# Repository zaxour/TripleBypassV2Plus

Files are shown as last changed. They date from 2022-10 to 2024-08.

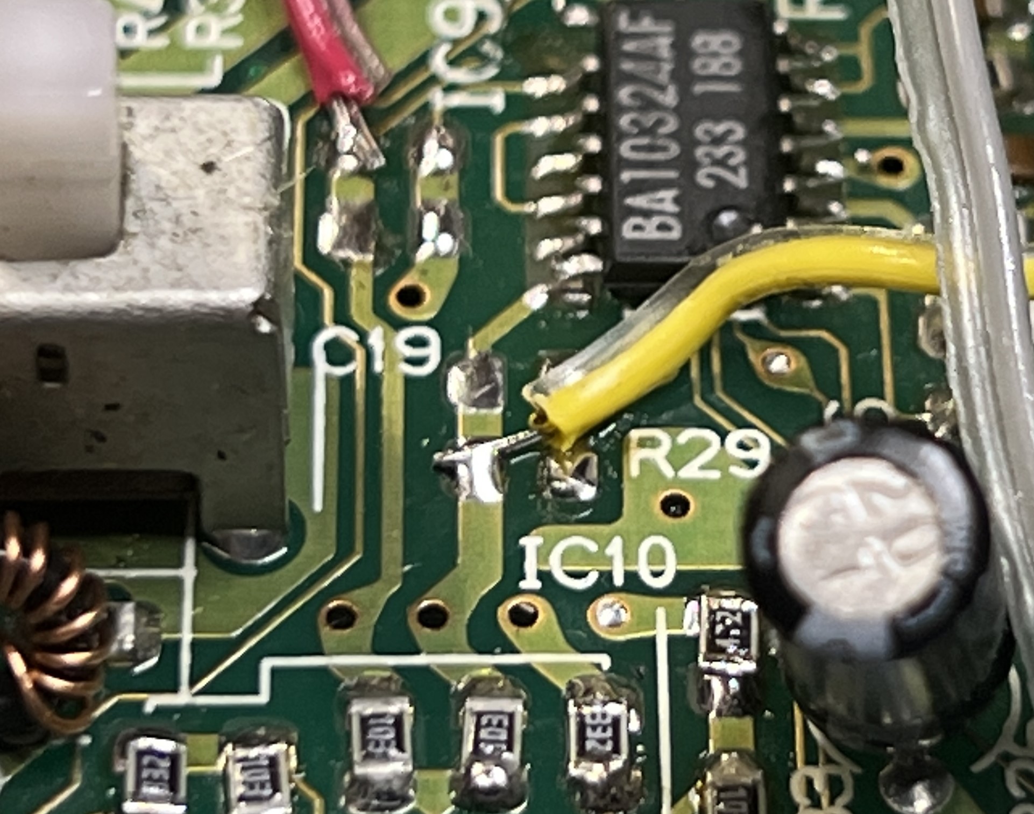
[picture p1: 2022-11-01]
images/Headphone Amp Connections.jpg

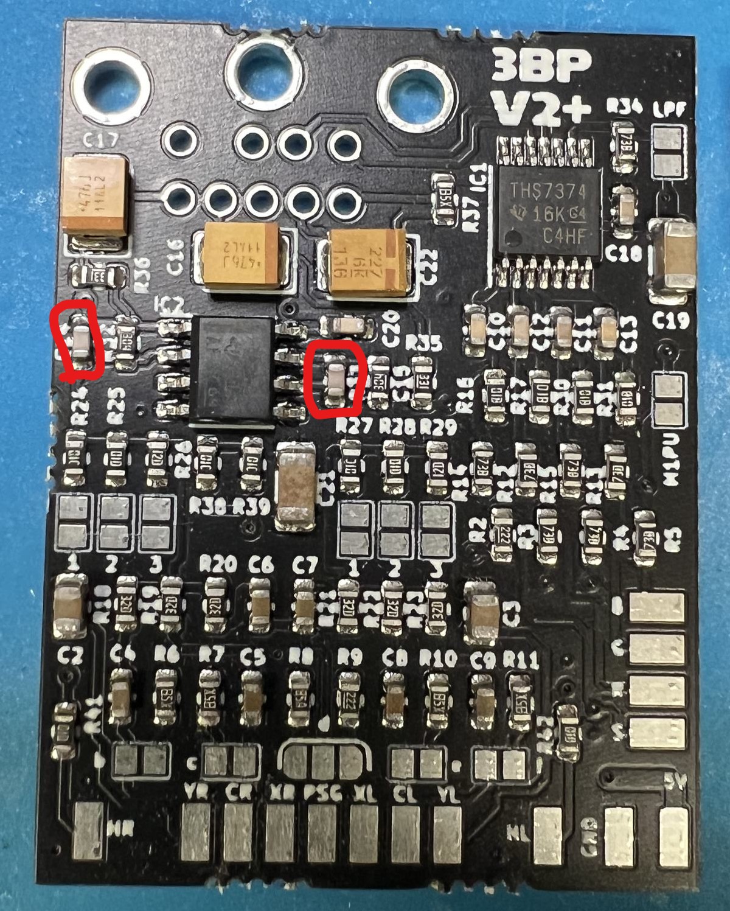
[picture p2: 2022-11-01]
images/3BP_RemoveCaps.jpg

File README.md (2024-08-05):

# Triple Bypass V2 Plus
My variant of Tian Feng's Triple Bypass V2, integrating pull up resistors and headphone restoration capability for Model 1 installs, as well as composite video restoration capability for all models.

All Genesis/Mega Drive revision instructions are linked below:

## Model 1 Installation Guides
[Model 1 - VA1-VA6](https://github.com/zaxour/TripleBypassV2Plus/blob/main/Documentation/3BP%20-%20M1VA0-VA6.pdf) 

[Model 1 - VA7](https://github.com/zaxour/TripleBypassV2Plus/blob/main/Documentation/3BP%20-%20M1VA7.pdf)
## Model 2 Installation Guides
[Model 2 - VA0-1.8](https://github.com/zaxour/TripleBypassV2Plus/blob/main/Documentation/3BP%20-%20M2VA0-1_8.pdf)

[Model 2 - VA2](https://github.com/zaxour/TripleBypassV2Plus/blob/main/Documentation/3BP%20-%20M2VA2.pdf)

[Model 2 - VA2.3](https://github.com/zaxour/TripleBypassV2Plus/blob/main/Documentation/3BP%20-%20M2VA2_3.pdf)

[Model 2 - VA3](https://github.com/zaxour/TripleBypassV2Plus/blob/main/Documentation/3BP%20-%20M2VA3.pdf)

[Model 2 - VA4](https://github.com/zaxour/TripleBypassV2Plus/blob/main/Documentation/3BP%20-%20M2VA4.pdf)

## Model 3 Installation Guides
[Model 3 - VA1](https://github.com/zaxour/TripleBypassV2Plus/blob/main/Documentation/3BP%20-%20M3VA1.pdf)

[Model 3 - VA2](https://github.com/zaxour/TripleBypassV2Plus/blob/main/Documentation/3BP%20-%20M3VA2.pdf)

## Sega CDX
[CDX](https://github.com/zaxour/TripleBypassV2Plus/blob/main/Documentation/3BP%20-%20CDX.pdf)

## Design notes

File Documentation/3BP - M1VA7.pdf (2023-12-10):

## Model 1 VA7 Procedure

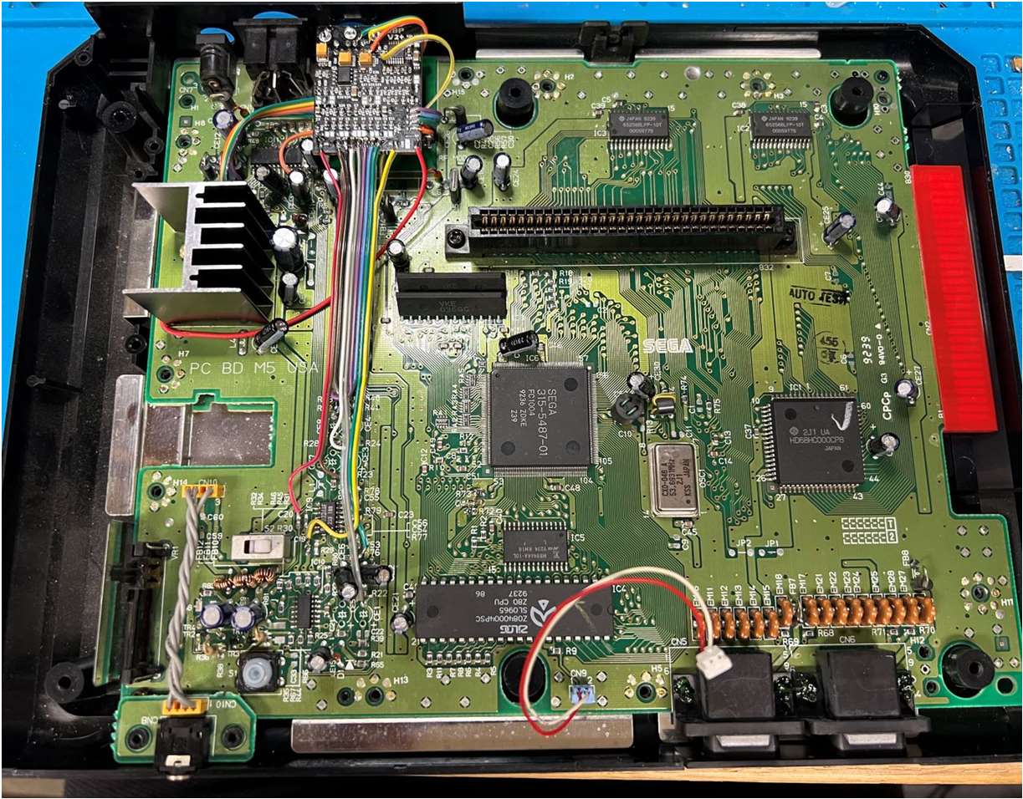
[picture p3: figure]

## Model 1 VA7 – Audio – Component Removal

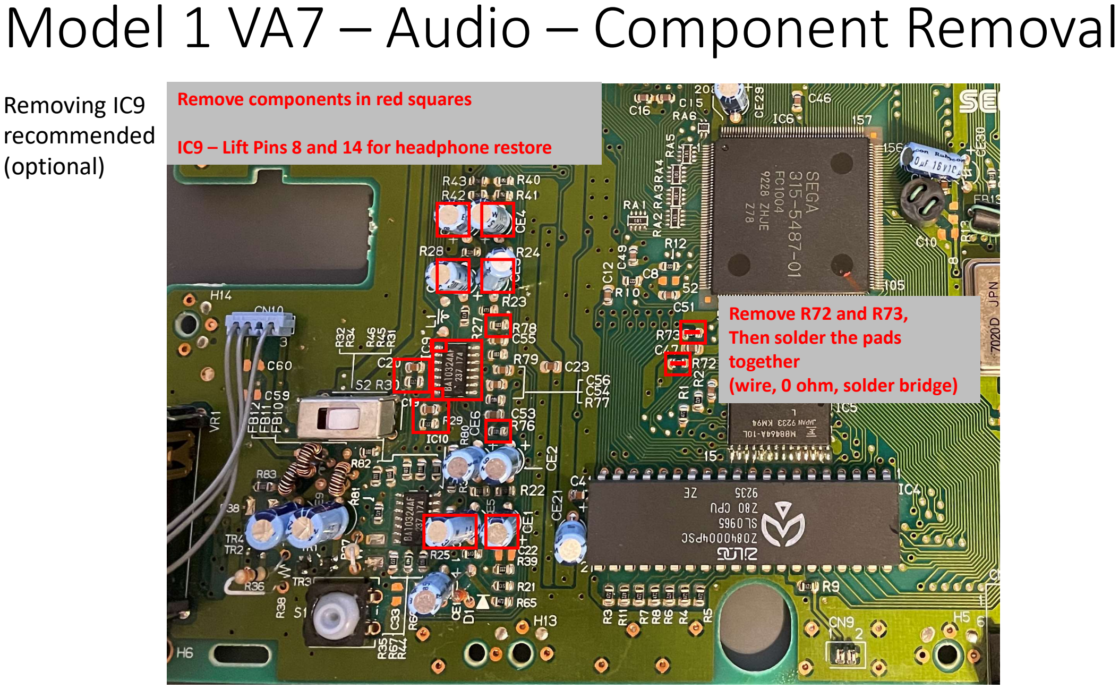
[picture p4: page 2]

Remove R72 and R73,
Then solder the pads
together
(wire, 0 ohm, solder bridge)

Remove components in red squares

IC9 – Lift Pins 8 and 14 for headphone restore

Removing IC9
recommended
(optional)

## Model 1 VA7 – Audio – Signal Points

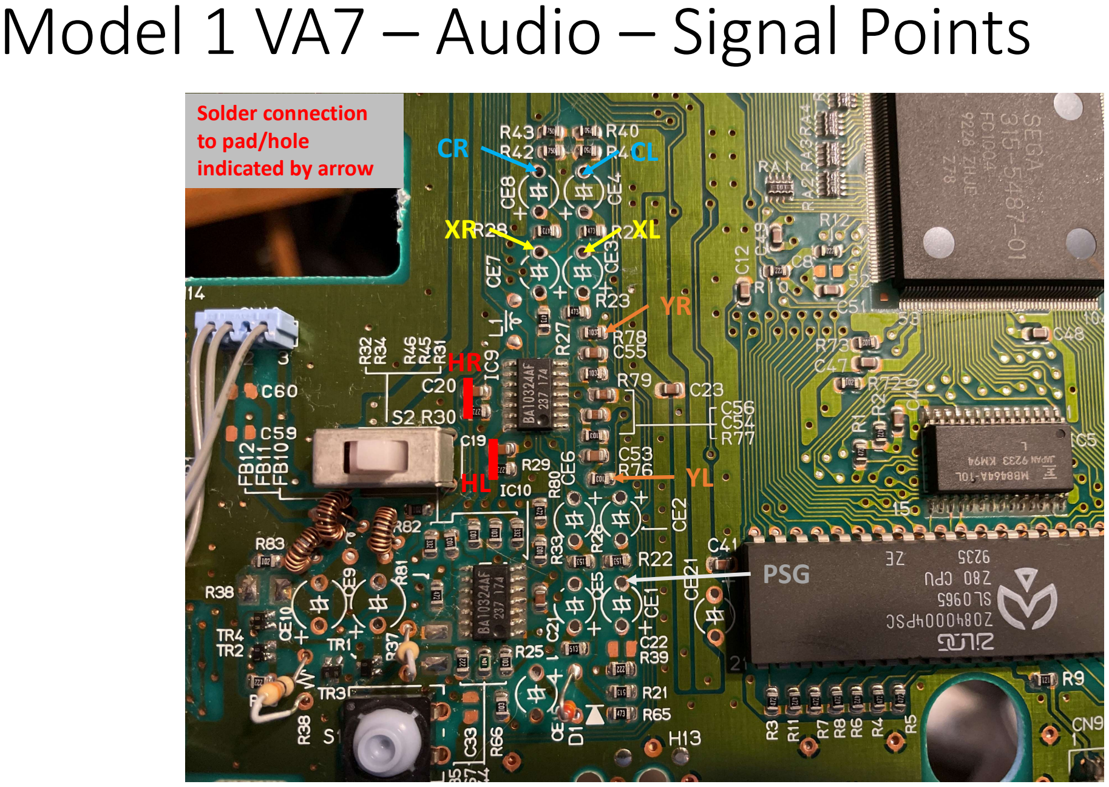
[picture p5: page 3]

CR | CL
XR | XL YR

YL

PSG

Solder connection
to pad/hole
indicated by arrow

HR

HL

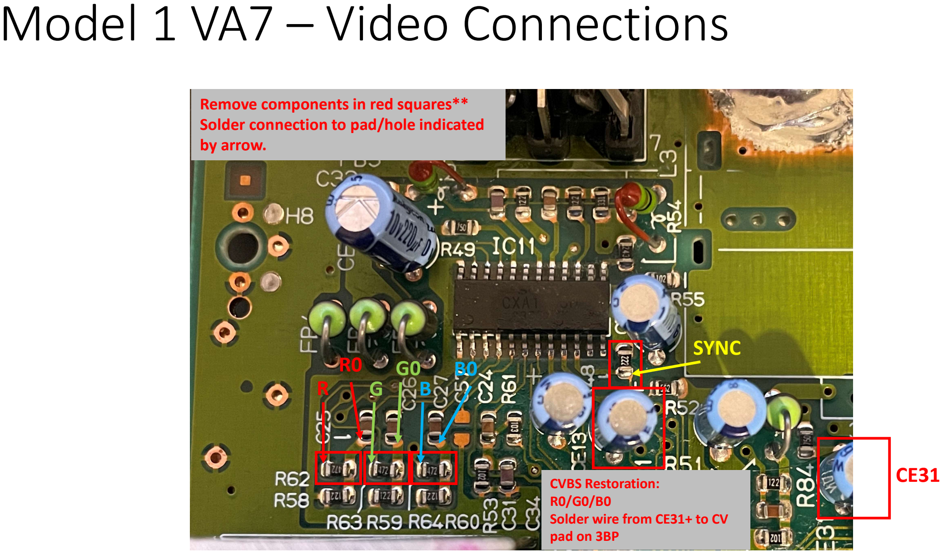
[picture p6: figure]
Model 1 VA7 – Video Connections; SYNC; Remove components in red squares** Solder connection to pad/hole indicated by arrow.; CVBS Restoration: R0/G0/B0 Solder wire from CE31+ to CV pad on 3BP

## Model 1 VA7 – Supply Voltage

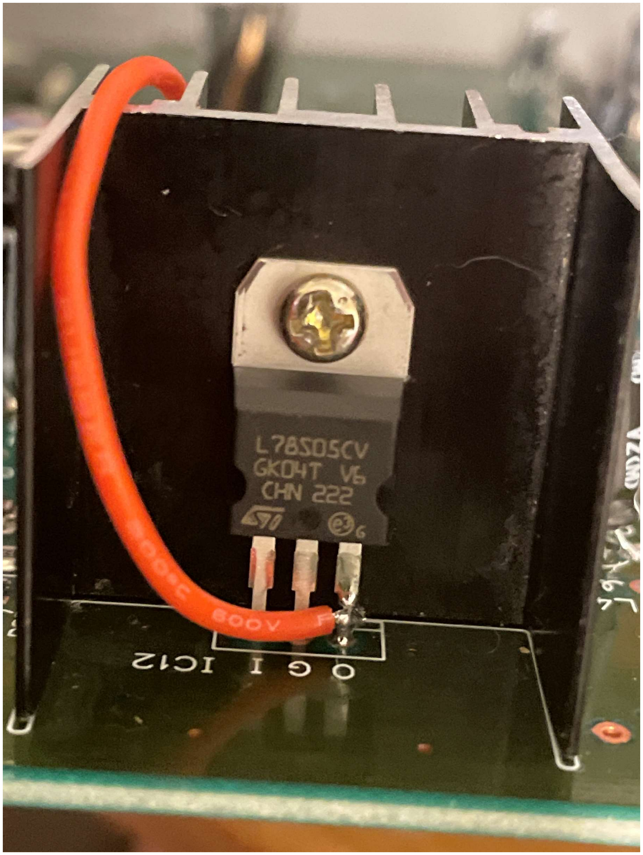
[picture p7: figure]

- Solder a wire from
the “O” (output) pin
of the 5V regulator
to the 5V pad on the
3BP to complete the
installation

## Model 1 VA7 – 3BP Jumpers and Wrap-Up

- ***If re-using the RF shield, remember to bend/cut any points that may contact the 3BP***
- Bridge the following solder jumpers:
- 2
- If NO CVBS restore – S75
- The other jumpers are unnecessary for this model using this guide.

## M1VA7 – Installation Complete w/ CVBS Restore and Headphone Restore

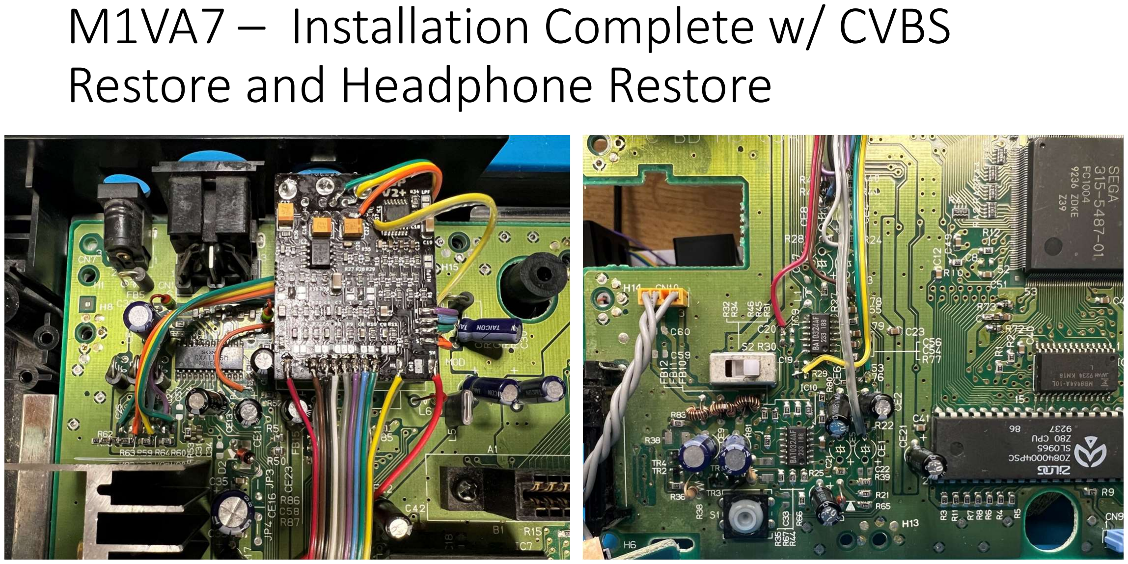
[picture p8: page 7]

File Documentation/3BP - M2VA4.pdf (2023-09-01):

# M2VA4 Procedure

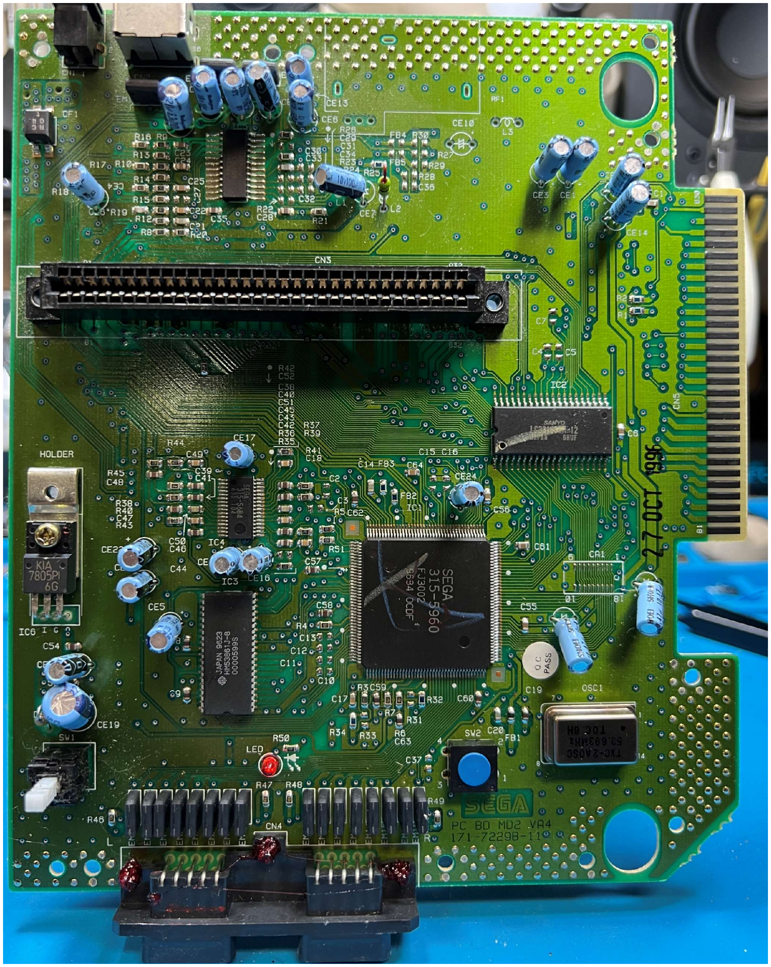
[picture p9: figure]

# M2VA4 – Audio – Component Removal

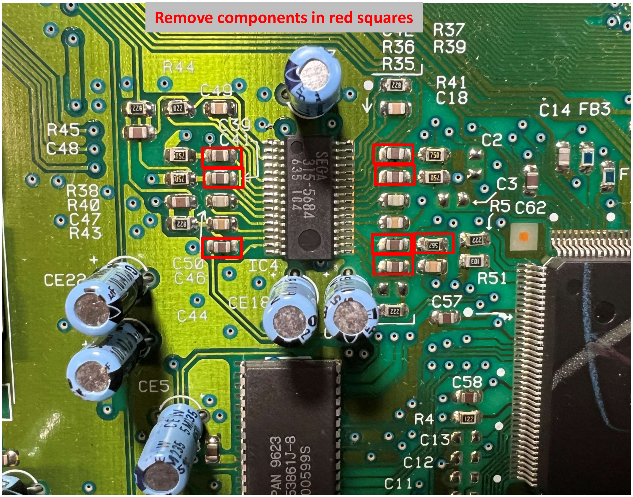
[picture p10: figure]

IC9 is required for | Remove components in red squares
system operation
(reset circuit,
reference voltage)

Also remove CE11-
12 (see Video
component
removal section)

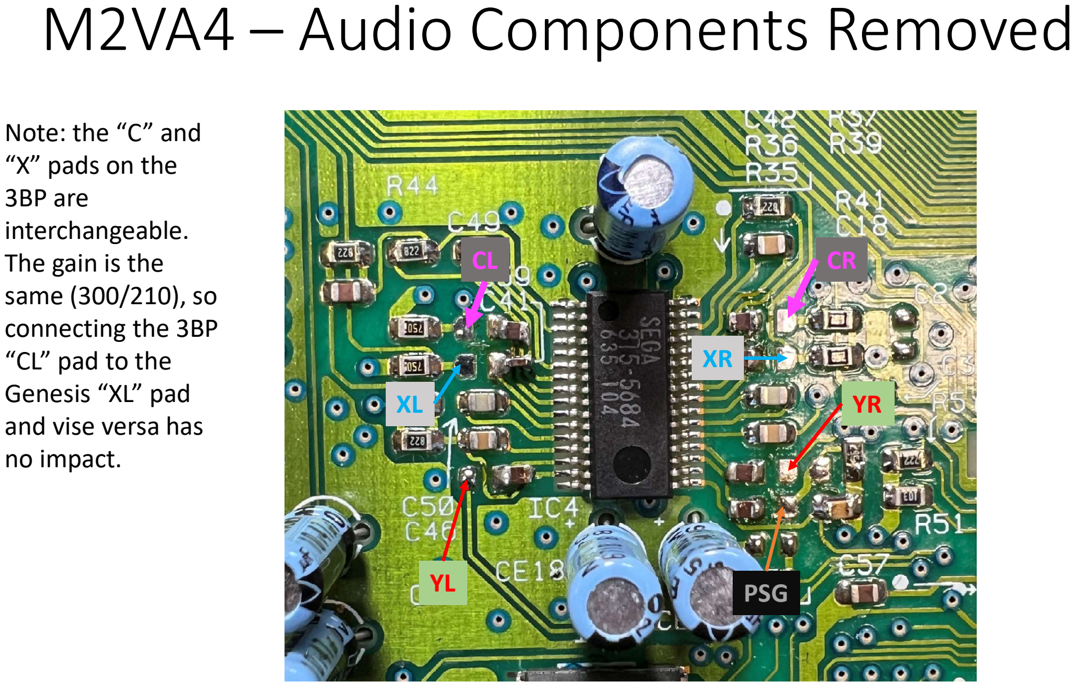
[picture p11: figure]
M2VA4 – Audio Components Removed; Note: the “C” and “X” pads on the 3BP are interchangeable. The gain is the same (300/210), so connecting the 3BP “CL” pad to the Genesis “XL” pad and vise versa has no impact.; PSG

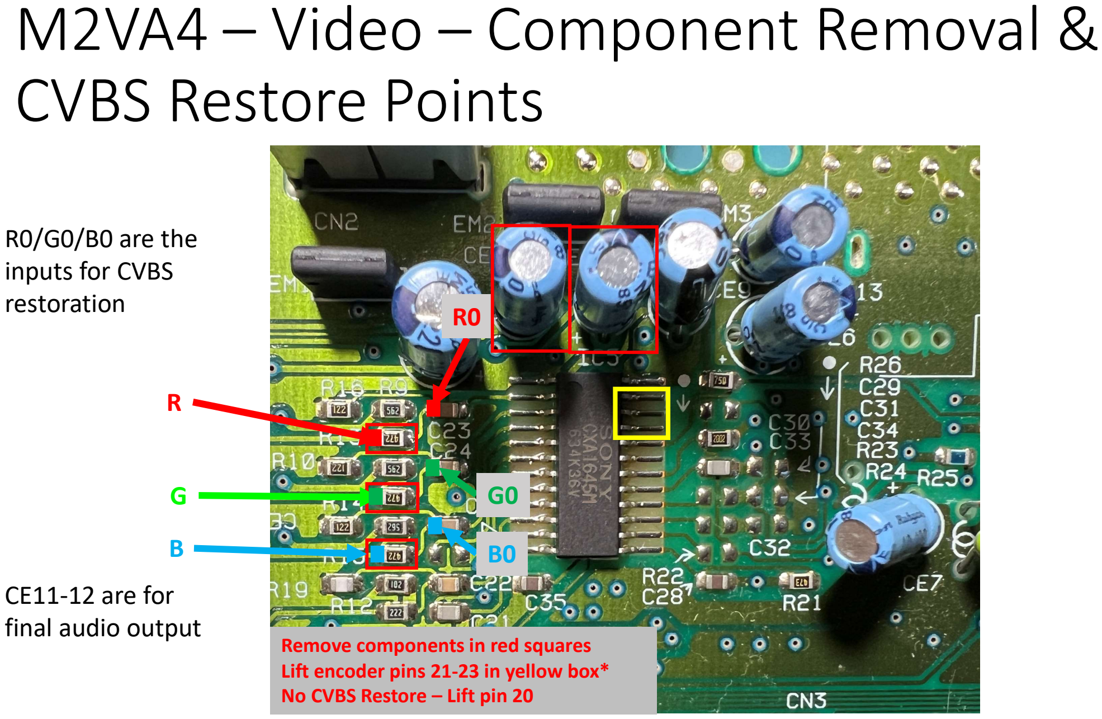
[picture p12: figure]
M2VA4 – Video – Component Removal & CVBS Restore Points; Remove components in red squares Lift encoder pins 21-23 in yellow box* No CVBS Restore – Lift pin 20; R0/G0/B0 are the inputs for CVBS restoration; CE11-12 are for final audio output

# M2VA4 – 3BP Jumpers

## - Solder the following jumpers:

## - 3 (both left and right) - D-Right - S75 if NOT restoring CVBS (V2A/V2+)

# M2VA4 Routing Complete

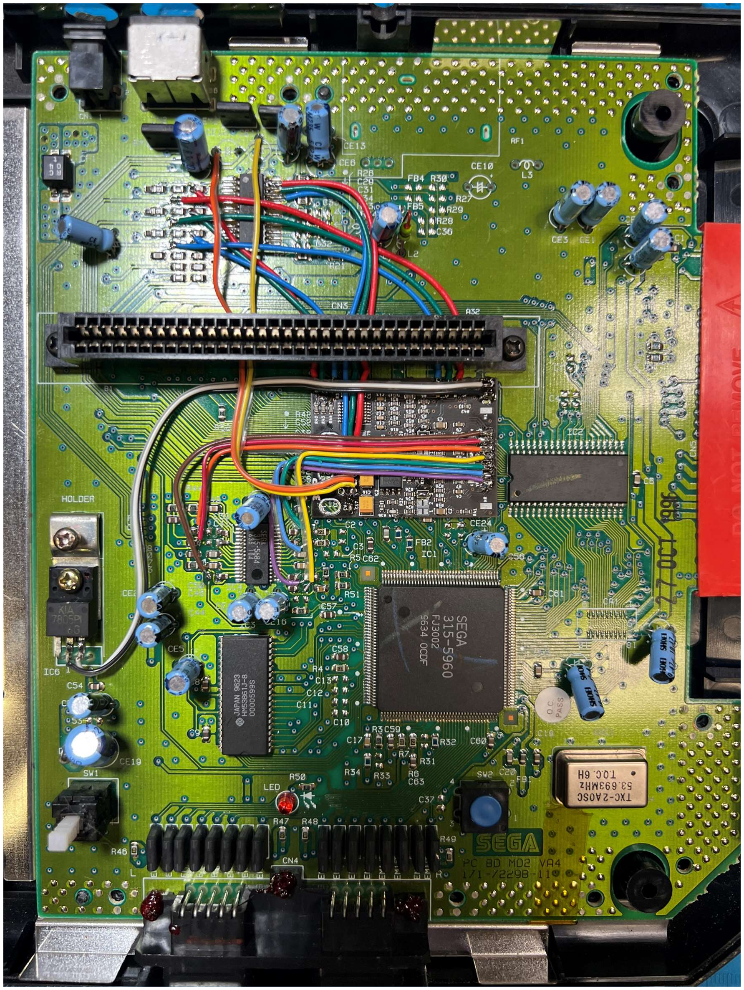
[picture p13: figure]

- If routing under the cart slot, it is
recommended to solder the RGB wires to the 3BP first, then pull the other end through the cart slot pins.

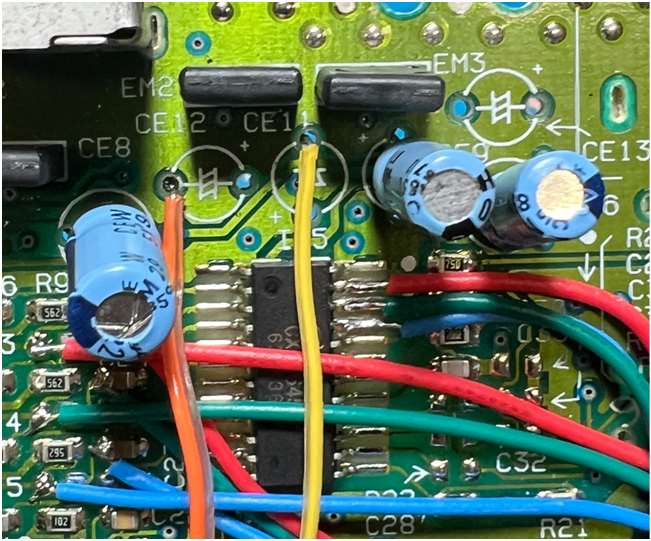
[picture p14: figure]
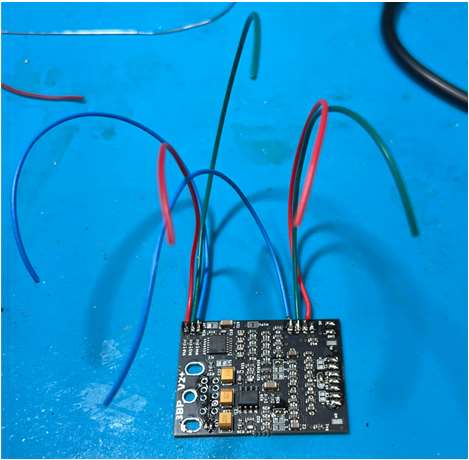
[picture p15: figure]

- CE11(-) – Right Audio
- CE12(-) – Left Audio

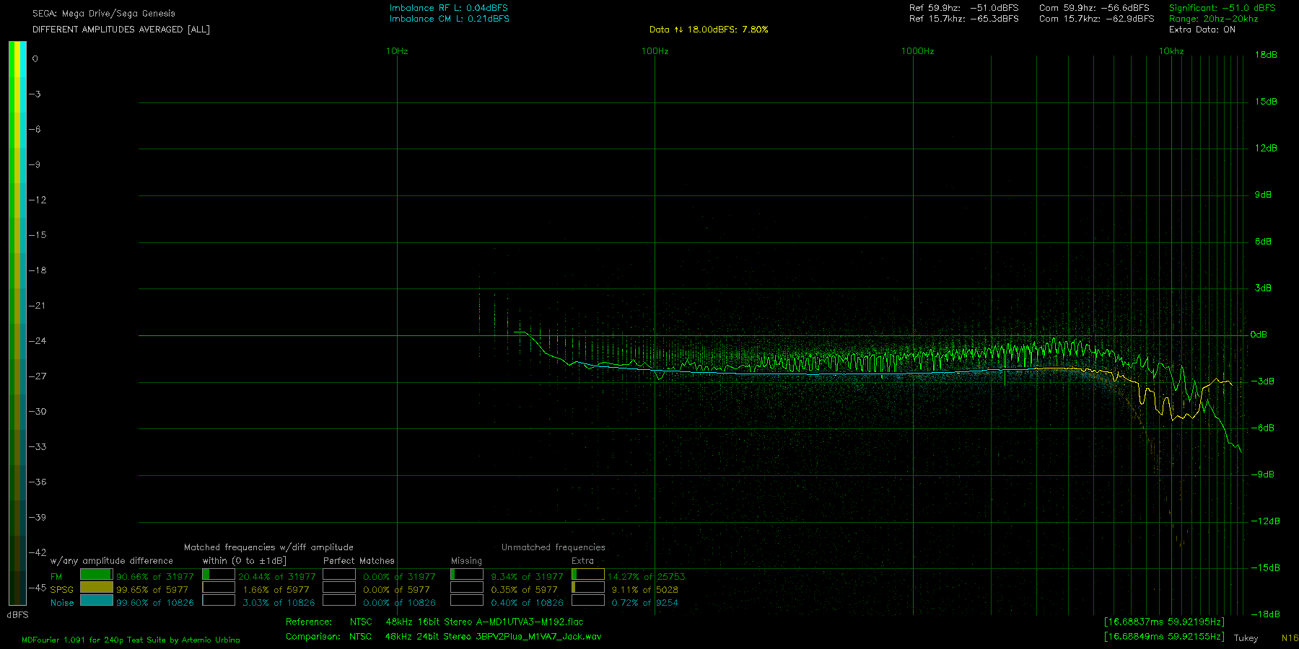
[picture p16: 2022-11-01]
images/DA__ALL_AVG_A-MD1UTVA3-M192_vs_3BPV2Plus_M1VA7_Jack_0000.png

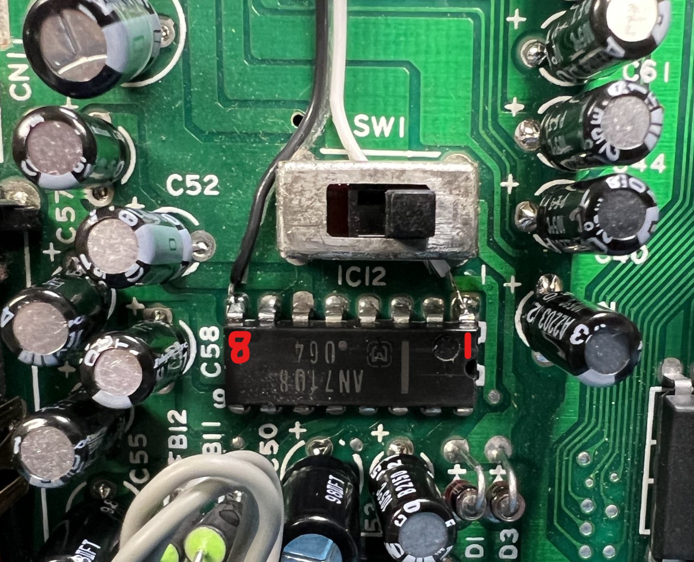
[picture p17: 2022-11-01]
images/VA3_HPAmp.jpg

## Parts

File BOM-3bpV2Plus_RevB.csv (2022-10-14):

Comment | Designator | Footprint | LCSC
220u | C22 | CP_EIA-3528-15_AVX-H | C122252
10u | C19,C21 | C_1206_3216Metric | C13585
0.1u | C10,C11,C12,C13,C18,C20 | C_0603_1608Metric | C14663
1u | C4,C5,C6,C7,C8,C9 | C_0603_1608Metric | C15849
10u | C2,C3 | C_0805_2012Metric | C15850
1k | R17,R30,R31 | R_0603_1608Metric | C21190
130k | R26,R29 | R_0603_1608Metric | C22795
210k | R18,R19,R20,R21,R22,R23 | R_0603_1608Metric | C22952
300k | R32,R33 | R_0603_1608Metric | C23024
330 | R35,R36 | R_0603_1608Metric | C23138
5.62k | R12,R13,R14,R15,R3,R34,R4,R5 | R_0603_1608Metric | C23188
750 | R8 | R_0603_1608Metric | C23241
100k | R25,R28,R41,R42 | R_0603_1608Metric | C25803
10k | R24,R27,R38,R39 | R_0603_1608Metric | C25804
THS7374IPWR | IC1 | TSSOP-14_4.4x5mm_P0.65mm | C2652746
150p | C14,C15 | C_0603_1608Metric | C37298
2.2k | R2,R9 | R_0603_1608Metric | C4190
75 | R10,R11,R6,R7 | R_0603_1608Metric | C4275
TL972 | IC2 | SOIC-8_3.9x4.9mm_P1.27mm | C46127
47u | C16,C17 | CP_EIA-3528-15_AVX-H | C7207
MD-90SM_MD2 | CN1 | MD90SM-MD2
SolderJumper_3_Open | D1 | SolderJumper-3_P1.3mm_Open_RoundedPad1.0x1.5mm
SolderJumper_2_Open | YR4 | SolderJumper-2
SolderJumper_2_Open | YR3 | SolderJumper-2
SolderJumper_2_Open | YR2 | SolderJumper-2
SolderJumper_2_Open | YL4 | SolderJumper-2
SolderJumper_2_Open | YL3 | SolderJumper-2
SolderJumper_2_Open | YL2 | SolderJumper-2
SolderJumper_2_Open | M1PU1 | SolderJumper-2
SolderJumper_2_Open | LPF1 | SolderJumper-2
SolderJumper_2_Open | F1 | SolderJumper-2
SolderJumper_2_Open | E1 | SolderJumper-2
SolderJumper_2_Open | C1 | SolderJumper-2
SolderJumper_2_Open | B_1 | SolderJumper-2
75 | R37 | R_0603_1608Metric
1k | R16 | R_0603_1608Metric
SolderJumper_2_Open | J4 | SolderJumper-2
511 | R43 | R_0603_1608Metric
511 | R44 | R_0603_1608Metric
511 | R40 | R_0603_1608Metric

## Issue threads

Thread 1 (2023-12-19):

180K resistors required for headphone audio restoration - VA6

p25dotca, 2023-12-19:
For VA6 console, I found it necessary  to utilize 180K resistors in series with the outputs of the TL972 to achieve proper audio levels from headphone connector. Directly connecting the L/R outputs from the TL972 to C42/C44 anode connections (+), results in severely distorted headphone audio on a VA6 with original 3BPV2 board.

To be clear:   TL972 pin 1 (R audio channel) --> 180K --> C44 (+),  TL972 pin 7 (L audio channel) --> 180K --> C42 (+).

All instructions in your guide were followed. The following components are removed on my VA6:

C40, C41, C42, C43, C44, C62, C62  (top side of PCB),  C45, C46, C47, C48, R34, R37 (bottom side of PCB)

I am happy with the results of the 180K resistors. However, it's possible 150K may offer slightly higher amplitude from headphone output, but my unscientific ears may have observed some remaining compression artifacts. I also experimented with 100K and 10K.  100K had noticeable compression artifacts on highly frequencies (such as Sonic picking up rings); 10K was severely distorted/compressed and is unusable.

zaxour, 2024-01-04:
I haven't experienced that myself, but looking at the schematics, the gain
for the signals on the 3BP for a model 1 should be:

FM - 30 (300k / 10k)
PSG/CD/EXP - 1.43 (300k/210k)

Since the gain resistors for headphone audio are 10K (R40, 41 va3), that
should knock the amplitude back down quite a bit, since everything will be
going through a 47K resistor (R38, R39 for VA3), which would set the
overall gain to ~0.18. Multiplying that by the original gain values puts
the overall gain back in the same territory as the original circuit
(10k/2.2k for FM, 10k/47k, 10k/51K for the others). That you would need
threefold the resistance to remove distortions might point to another
problem. Would you mind sending photos of your install to "zaxour" via
gmail? It's possible that the ref-des got updated between revisions and the
wrong resistors may have been removed, which  means I need to update my
instructions. Thanks!

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

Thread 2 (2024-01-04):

Gerber for the VDP relief board

OlivierGrimard, 2024-01-04:
Hi @zaxour , could you please add the gerber file for the VDP relief board? I would like to try it because this part is not easy to solder and I think it will help a lot for the installation.

Thank you.
Olivier

zaxour, 2024-01-04:
Hi,

It’s available here:

https://github.com/zaxour/M1ReliefBoard

Hope this helps!

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

OlivierGrimard, 2024-01-04:
Thank you :)

Closed 2024-01-04.

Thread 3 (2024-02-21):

Sega Genesis TripleBypass M2VA3 Missing Pic

tmcbity, 2024-02-21:
Hello,

Hope this message finds you well.

It appears that your Genesis TripleBypass M2VA3 instructions are missing a picture under the "M2VA3- 3BP Jumpers" heading. Am I possibly missing something?

Thank you so much for putting these instructions together!

Also, thank you for your time!

zaxour, 2024-02-21:
Hi,

The lack of a picture was intentional. You only need to solder the "2"
jumpers (both of them) for the Model 2 VA3 installation.

Although, thinking about it, having a labeled diagram of the board with
those highlighted might make it more clear.

Thanks,
Zack

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

tmcbity, 2024-02-24:
Thank you so much good sir, you are awesome.

My apologies for the stupid question. I am a beginner hobbyist and I really want to learn. I have a background in engineering, just not electronics.

Last question:

I noticed that I received 3 resistors with the sega triple bypass (retrorbg - I tried ordering from you, but you were out of stock). Are these just for the model 1? Are they necessary for the model 2? I understand that the bypass does not properly replicate the Sega RGB circuit in the model 1, which includes 3 resistors. Is this also an issue for the model 2?

Thank you so much!

Igor Koracin

zaxour, 2024-02-24:
Igor,

Yes, those should be 5.6K resistors and are only necessary on model 1 installs, since the VDP RGB pins are typically lifted and thus the open collector outputs of the VDP are no longer properly loaded. A model 2 install does not require them unless it is desired to lift the RGB pins for some reason.

Zack
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

tmcbity, 2024-02-24:
Thank you so much for the prompt response and information, my friend. Anything cool I can purchase from your store that you suggest? I'm a collector and have most consoles.

Closed 2024-02-24.

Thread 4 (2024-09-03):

VA7 HR and HL connections

ImaSeven, 2024-09-03:
Having trouble seeing where you have the HR and HL wires connected onto the board.  Can you give me more information or clearer pictures.  Thank you

ImaSeven, 2024-09-03:
I just noticed the board I have does not have those connections on it.  Is it possible to do this without? Or can you supply a link to one I can purchase? Thanks

ImaSeven, 2024-09-03:
Nevermind I'm stupid and found your kofi shop.

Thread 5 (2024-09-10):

Md2 va0-1.8 documentation jumpers

duncan1111, 2024-09-10:
Just wanting to clarify the correct jumpers for a MD2 va0.

In the documentation it says to jump 2, C & E.

On the back of the Pcb - on the silk screen is only says to jump 2.

Which is correct?

Thanks

zaxour, 2024-09-11:
The documentation is correct. The MD2VA0 does not have the 75 ohm
termination resistors for cartridge/32X audio, thus the need for jumpers C
& E.

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

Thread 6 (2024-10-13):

Sega CDX sound issues

TruREALigion, 2024-10-13:
2 questions:

1.
I seem to have ruined the pad for PSG.  Is there an alternative spot I can wire up to?

2.
On the section where I wire up SR and SL I did not change/replace R75 and R76 to 4.7K  That are originally 11K (code113).  Is this critical to change?

My current issues are:
-Cartridge games no sound
-Sega CD BIOS screen has weird sounds (maybe related to PSG not wired as per the install guide?)
-Sega CD BIOS “Sonic screen” where the game loads has no sound (where the sparkle chime from left to right plays).

CD sound is perfect however.

zaxour, 2024-10-13:
I would need to see photos of your install to troubleshoot.

Zack
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

TruREALigion, 2024-10-13:
> I would need to see photos of your install to troubleshoot. Zack
> […](#)
> On Oct 12, 2024 at 21:45 -0600, TruREALigion ***@***.***>, wrote: I followed the guide, but did not change/replace R75 and R76 to 4.7K. That are originally 11K (code113). would this be the reason I am not getting sound? — Reply to this email directly, view it on GitHub, or unsubscribe. You are receiving this because you are subscribed to this thread.Message ID: ***@***.***>

I realized this isn’t even your board so I will reach out to Tienfeng.  I have yet to figure out where to connect PSG because I broke the pad…

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

zaxour, 2024-10-13:
The connections should be the same. Make sure you’re testing with the CD board attached.

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

TruREALigion, 2024-10-14:
> The connections should be the same. Make sure you’re testing with the CD board attached.
> […](#)
> On Oct 13, 2024 at 11:43 -0600, TruREALigion ***@***.***>, wrote: > I would need to see photos of your install to troubleshoot. Zack > … > On Oct 12, 2024 at 21:45 -0600, TruREALigion @.>, wrote: I followed the guide, but did not change/replace R75 and R76 to 4.7K. That are originally 11K (code113). would this be the reason I am not getting sound? — Reply to this email directly, view it on GitHub, or unsubscribe. You are receiving this because you are subscribed to this thread.Message ID: @.> I realized this isn’t even your board so I will reach out to Tienfeng. I have yet to figure out where to connect PSG because I broke the pad… IMG_9332.jpeg (view on web) — Reply to this email directly, view it on GitHub, or unsubscribe. You are receiving this because you commented.Message ID: ***@***.***>

Yeah the console turns on fine, sound (32X. CD) in general works, just that I did not replace R75 and R76, and the PSG i connected to a different spot on the back of the board (which is probably incorrect).
Do you happen to know if R75/R76 is a requirement to replace?

zaxour, 2024-10-15:
It would just increase the gain on the cartridge audio stuff, but if you're
getting 32X sound, that would mean that there's an issue with your FM
audio, since the 32X audio also goes through the same paths.

On Mon, Oct 14, 2024 at 10:41 AM TruREALigion ***@***.***>
wrote:

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

TruREALigion, 2024-10-16:
I have resolved all sound issues by successfully probing another point for the PSG signal on the rear.  Hopefully nobody has to do this because of my mistake of breaking the pad!
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

Closed 2024-10-16.

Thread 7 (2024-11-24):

Sega CDX - HD Retrovision cables scrambled video (with color).

TruREALigion, 2024-11-24:
RGBS SCART works fantastic. No jailbars. Sound is amazing. 32x works, CD sound works.
However, I am having trouble getting HD Retrovision cables to work.  The picture is all "scrambled".  On an OSSC LCD, it gets sync on and off every second.

Your instructions does not include wiring up Sync (S) on the board (Only R,G, and B) because C-Sync (9-DIN Pin5) is coming from R37 and C-Video (Pin 4) is coming from C46 negative.  In my case, I left R37 and C46 untouched
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

I believe HD Retrovision cables are Sync-on-Composite so this is where I tried experimenting:
- I connected S75 output on the 3BP to C46 negative. I also tried totally removing C46 so that S75 goes directly to PIN 5.  Result is the same scrambled video no matter what combinations I tried.
- I removed R37, which means I do not get any C-Sync, so as expected = black screen.
- I left R37 removed, and added Sync (S) to the 3BP board via pin 42 on the VDP (315-5660).  Sync output direct to pin 4 on DIN.  And scrambled video again.  I was unable to find any potential pull-up resistors (maybe it doesn't exist for ASIC models?).  I know Pin 42 on the VDP goes to Pin 10 of the RGB encoder.

Is there anything else I can try?

TruREALigion, 2024-11-25:
ok nevermind I got it working by connecting C-Sync directly to the pin5.  There was some unlabeled component just before PIN5 that was probably the cause of my problems.
I referenced this photo:
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

All is well!

Closed 2024-11-25.

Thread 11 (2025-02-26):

Japanese VA1 audio issues

HMNx98, 2025-02-26:
I'm trying to install to a Model 1 Japanese VA1, but the audio is pretty badly distorted through the headphones.

For the headphones resistor, which is 100k in the BOM, I have it replaced to 10K and connected to C42+ and C44+ as per the guide. All of the audio components removed are also as per the guide.

After the install that, I noticed that although the guide states Model 1 VA0-VA6, the steps actually say VA2-VA6. Is the headphones restore not possible on the VA1?

I found this post on consolemods which references this issue but some of the components they state to add/remove are part of the 3BP guide so I'm not sure exactly which to remove/swap out. https://consolemods.org/wiki/Genesis:Preamp_Fix_(Model_1)

Any tips would be greatly appreciated.

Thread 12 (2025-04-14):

VA6 - Jailbars

TruREALigion, 2025-04-14:
Hello Zaxour

I cannot, for the life of me, get rid of the jail bars on the M1VA6.

Not sure if this applies to me, but near the end of the instructions, it mentions something about 5.6K resistors to connect to +5V on the 3BP board

Notes:

- Red v2 3BP board
- lifted VDP pins RGB (Pin 27, 28, 29) to connect to 3BP RGB Input
- No relief board for VDP, not sure if this is required because instructions mentions connecting GND to C72 (-)
- I tried adding SMD cap for the subcarrier but did not resolve
- tried adding SMD cap nenar the VIAs as per Bob's article but same thing no difference [https://www.retrorgb.com/genesis1rgbbypass.html](url)

Other than that, everything is working, head phone restored, did not restore composite.

Any thoughts?  I feel like something about recreating 5V pull-ups after lifting the RGB pins on the VDP is the key?

zaxour, 2025-04-14:
Hi,

You do need the 5.6K pull up resistors for the RGB signals since those are
open collector outputs and having no pull-ups causes a missing color step.

For the jailbars, you *need* the relief board since it provides reference
plane field coupling for the adjacent VRAM traces, which are the source of
jailbars on the model 1. Adding the SMD caps has no effect on this problem.
if you aren't restoring composite, have you tried lifting the subcarrier
pin to remove it from the circuit altogether?

On Mon, Apr 14, 2025 at 8:22 AM TruREALigion ***@***.***>
wrote:

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

TruREALigion, 2025-04-14:
gotcha.

I did not try lifting the subcarrier pin, but for the sake of having a cleaner install, I will use your gerber file and get a relief board.

I'll keep this issue open until I complete the install with the relief board!

TruREALigion, 2025-04-21:
So I got the relief board, but still no difference with the jailbars.  I believe it isn't made by you, but could this be an issue with the Red (Open source?) v2 3BP board?

- Relief board soldered GND to C72 negative
- Probably not related, but CSYNC is coming directly from pin 42 of the VDP 315-5313 (instead of pin 10 of the CXA-1145 as per your instructions)
- R16 pull-up resistor for CSYNC is removed as per your instructions

Other than the visible jailbars (via Retrotink 4K) colors are vibrant.  Needless to say, it looks beautiful on a PVM/CRT.  Perhaps the problem is my console board.

Any thoughts?

zaxour, 2025-04-23:
Could you provide some photos of the install?

On Mon, Apr 21, 2025 at 3:20 PM TruREALigion ***@***.***>
wrote:

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

TruREALigion, 2025-05-03:
Hello see below install photos.  Let me know if you need a better view of somewhere.

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

zaxour, 2025-05-04:
It doesn’t seem like the relief board is flat to the main board surface, and then the RGB wires to the 3BP are pretty close to the VRAM, which could be polluting the input signal. I would suggest to clean/shorten up the wiring where possible.
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

TruREALigion, 2025-05-05:
Thank you for the suggestions but it hasn’t resolved it.

I have shortened the wiring to the relief board and flattened it down to the motherboard.

I also tried raising the 3BP board high up into the air as the console powers on.

Wondering if this is an issue with my Genesis.  Or perhaps I should just use your 3BPv2+ board to connect directly to the DIN.

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

Closed 2025-05-06.

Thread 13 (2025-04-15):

Dim/washed out Colors - Genesis 3 VA2

TruREALigion, 2025-04-15:
Hi Zaxour

I am installing your V2+ 3BP board on the M3VA2 and colors do not look correct.  It looks like the red’s are not deep enough.   I confirmed that my other 3BP Model 1 and CDX are fine (it’s not the cables). Sound is fantastic no issues

Here are pictures of my install:

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

zaxour, 2025-04-15:
It almost appears as if your red wire is bridging the gap there - double check your solder work there. Otherwise I don’t see anything particularly wrong.
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

TruREALigion, 2025-04-16:
And you are correct!  bridged the Red cable.  Sorry!

Closed 2025-04-16.

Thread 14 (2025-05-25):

CV pad missing

todorko985, 2025-05-25:
Hello,

Why my board dont have CV pad?

https://ibb.co/JFbVSxXJ

zaxour, 2025-05-25:
That looks like an older version before I added the CV pad. You can solder the CV wire to the positive side of the right most tantalum capacitor.
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

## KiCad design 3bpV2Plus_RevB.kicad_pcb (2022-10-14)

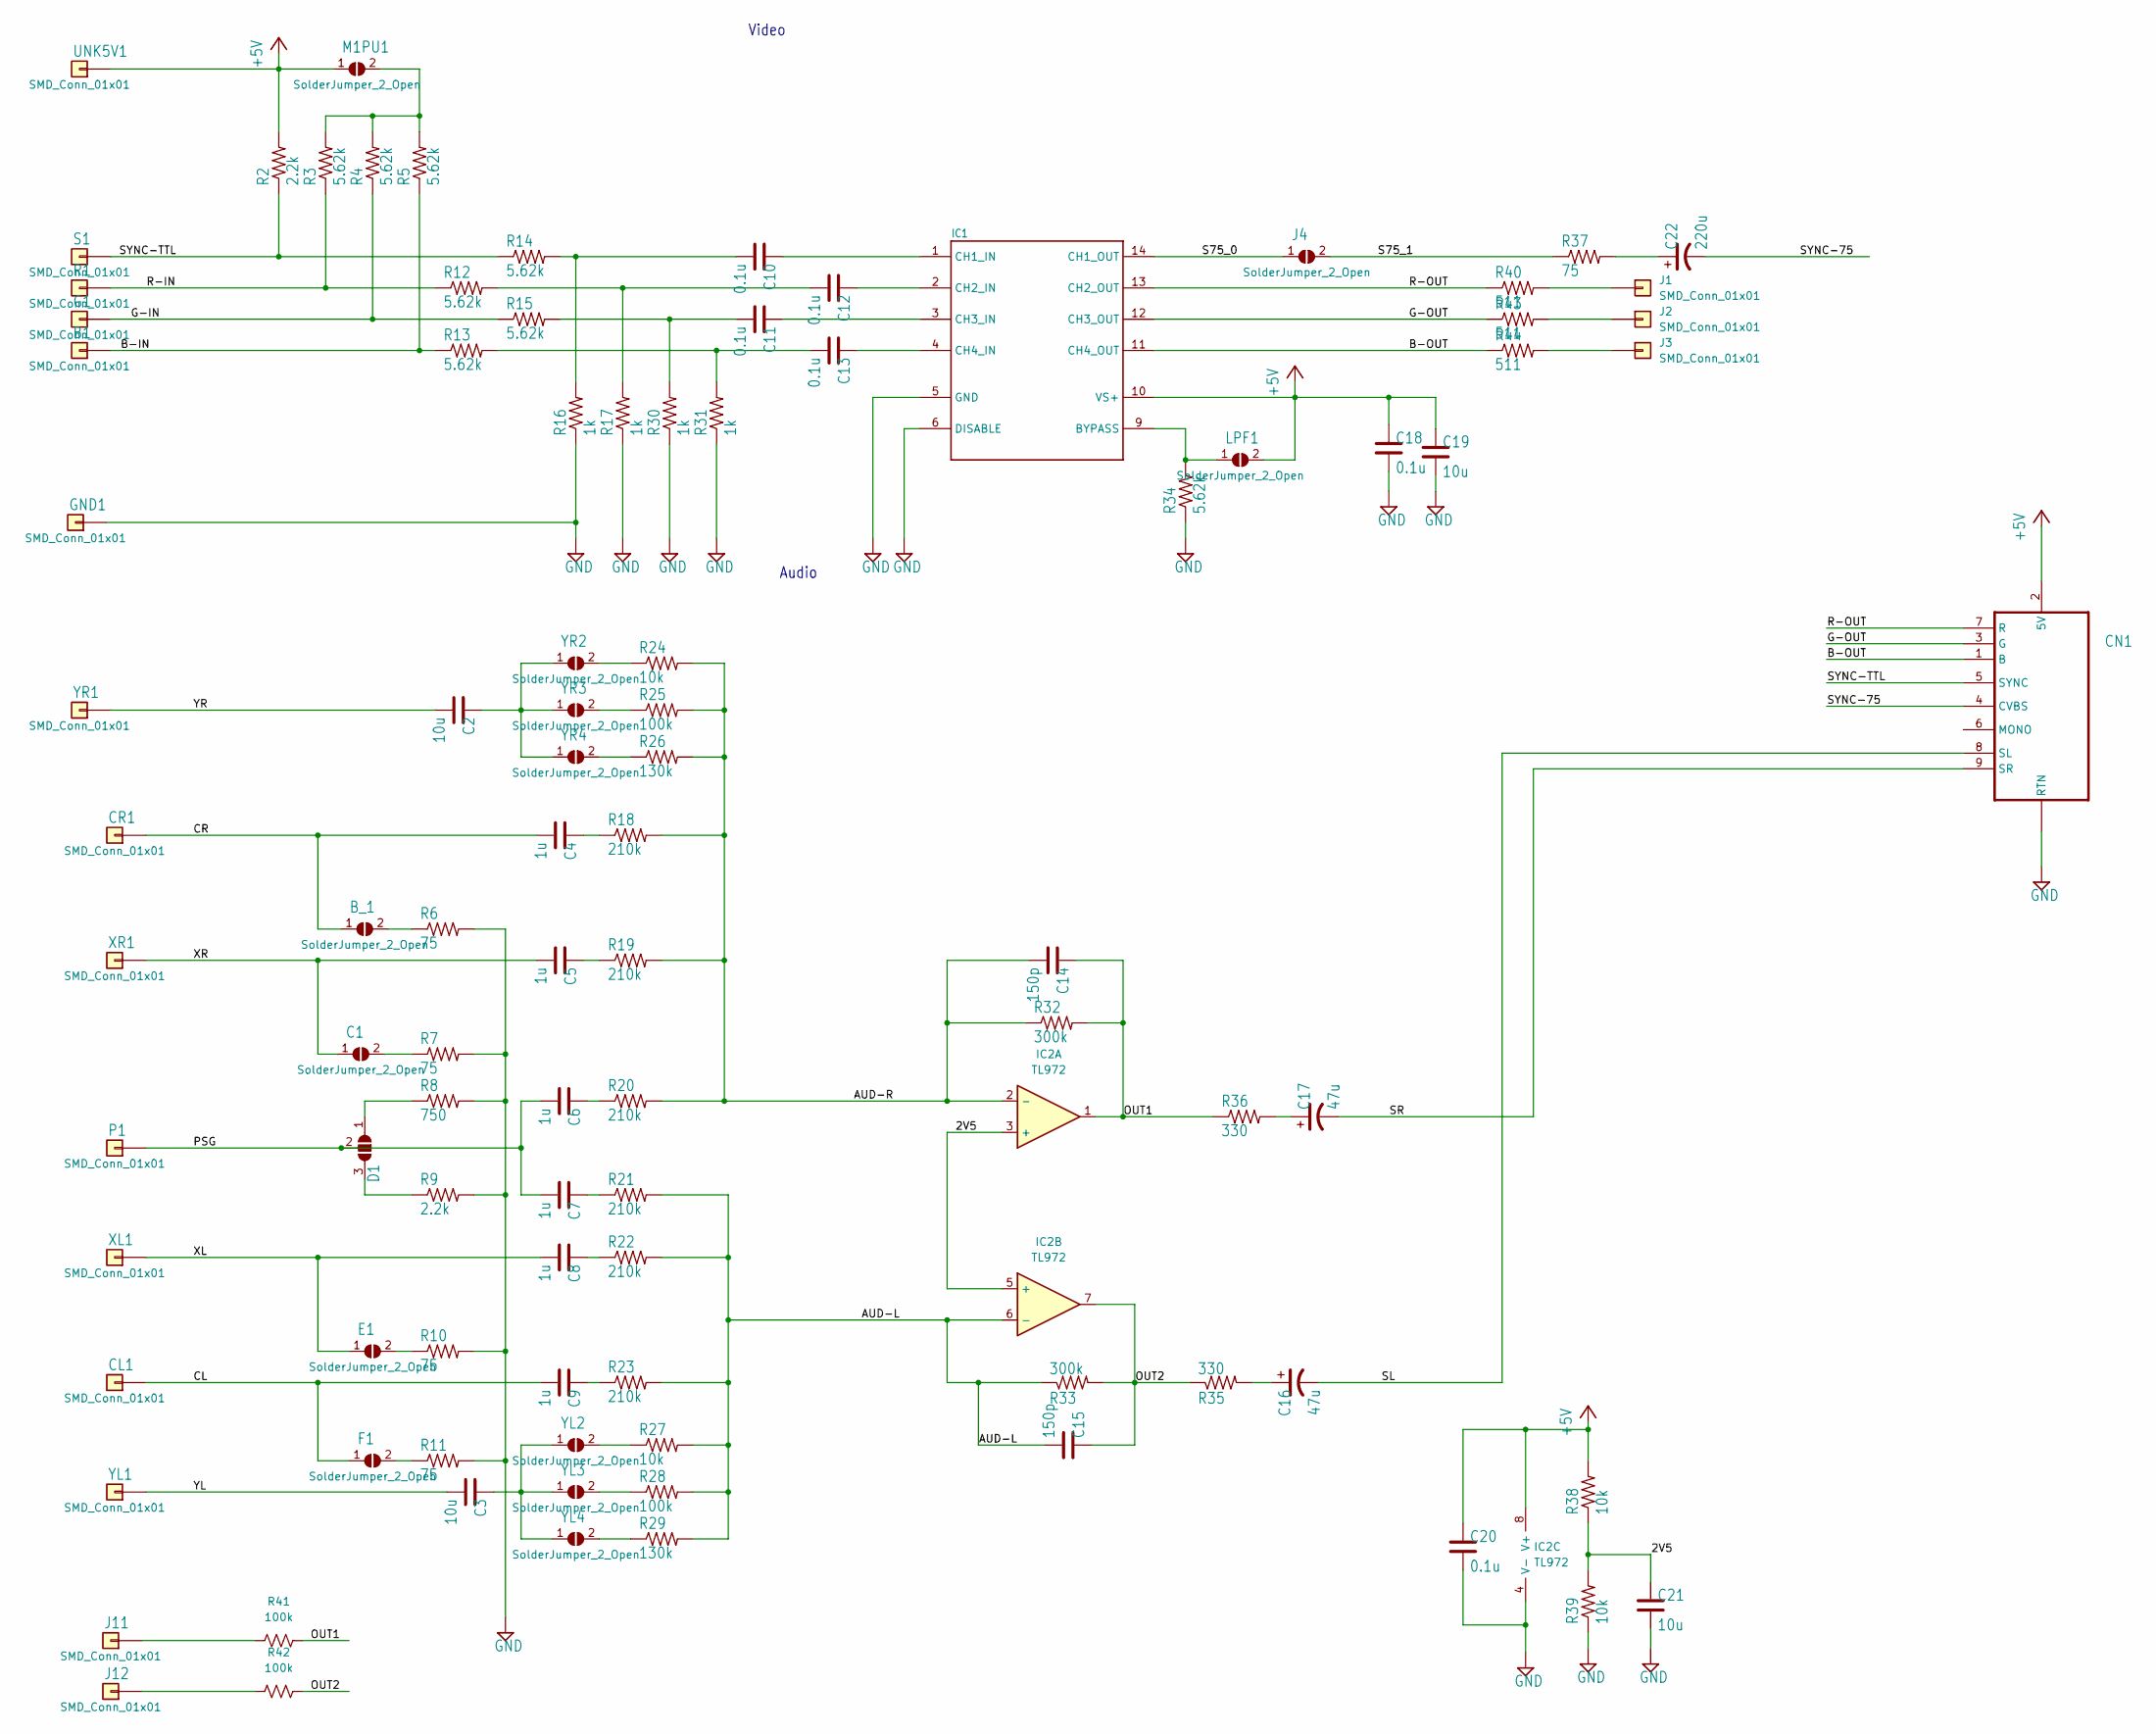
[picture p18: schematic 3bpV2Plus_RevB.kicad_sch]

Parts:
B1: SMD_Conn_01x01; SolderWirePad_1x01_SMD_1x2mm
B_1: SolderJumper_2_Open; SolderJumper-2
C1: SolderJumper_2_Open; SolderJumper-2
C2, C3: 10u; C_0805_2012Metric
C4, C5, C6, C7, C8, C9: 1u; C_0603_1608Metric
C10, C11, C12, C13, C18, C20: 0.1u; C_0603_1608Metric
C14, C15: 150p; C_0603_1608Metric
C16, C17: 47u; CP_EIA-3528-15_AVX-H
C19, C21: 10u; C_1206_3216Metric
C22: 220u; CP_EIA-3528-15_AVX-H
CL1: SMD_Conn_01x01; SolderWirePad_1x01_SMD_1x2mm
CN1: MD-90SM_MD2; MD90SM-MD2
CR1: SMD_Conn_01x01; SolderWirePad_1x01_SMD_1x2mm
D1: SolderJumper_3_Open; SolderJumper-3_P1.3mm_Open_RoundedPad1.0x1.5mm
E1: SolderJumper_2_Open; SolderJumper-2
F1: SolderJumper_2_Open; SolderJumper-2
G1: SMD_Conn_01x01; SolderWirePad_1x01_SMD_1x2mm
GND1: SMD_Conn_01x01; SolderWirePad_1x01_SMD_1x2mm
IC1: THS7374IPWR; TSSOP-14_4.4x5mm_P0.65mm
IC2: TL972; SOIC-8_3.9x4.9mm_P1.27mm
J1, J2, J3, J11, J12: SMD_Conn_01x01; SolderWirePad_1x01_SMD_1x2mm
J4: SolderJumper_2_Open; SolderJumper-2
LPF1: SolderJumper_2_Open; SolderJumper-2
M1PU1: SolderJumper_2_Open; SolderJumper-2
P1: SMD_Conn_01x01; SolderWirePad_1x01_SMD_1x2mm
R1: SMD_Conn_01x01; SolderWirePad_1x01_SMD_1x2mm
R2, R9: 2.2k; R_0603_1608Metric
R3, R4, R5, R12, R13, R14, R15, R34: 5.62k; R_0603_1608Metric
R6, R7, R10, R11, R37: 75; R_0603_1608Metric
R8: 750; R_0603_1608Metric
R16, R17, R30, R31: 1k; R_0603_1608Metric
R18, R19, R20, R21, R22, R23: 210k; R_0603_1608Metric
R24, R27, R38, R39: 10k; R_0603_1608Metric
R25, R28, R41, R42: 100k; R_0603_1608Metric
R26, R29: 130k; R_0603_1608Metric
R32, R33: 300k; R_0603_1608Metric
R35, R36: 330; R_0603_1608Metric
R40, R43, R44: 511; R_0603_1608Metric
S1: SMD_Conn_01x01; SolderWirePad_1x01_SMD_1x2mm
UNK5V1: SMD_Conn_01x01; SolderWirePad_1x01_SMD_1x2mm
XL1: SMD_Conn_01x01; SolderWirePad_1x01_SMD_1x2mm
XR1: SMD_Conn_01x01; SolderWirePad_1x01_SMD_1x2mm
YL1: SMD_Conn_01x01; SolderWirePad_1x01_SMD_1x2mm
YL2, YL3, YL4: SolderJumper_2_Open; SolderJumper-2
YR1: SMD_Conn_01x01; SolderWirePad_1x01_SMD_1x2mm
YR2, YR3, YR4: SolderJumper_2_Open; SolderJumper-2

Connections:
+5V: C18.1, C19.1, C20.1, CN1.2 (5V), IC1.10 (VS+), IC2.8 (V+), LPF1.2 (B), M1PU1.1 (A), R2.2, R38.2, UNK5V1.1
/2V5: C21.1, IC2.3 (+), IC2.5 (+), R38.1, R39.2
/AUD-L: C15.2, IC2.6 (-), R21.2, R22.2, R23.2, R27.2, R28.2, R29.2, R33.1
/AUD-R: C14.2, IC2.2 (-), R18.2, R19.2, R20.2, R24.2, R25.2, R26.2, R32.1
/B-IN: B1.1, R5.1, R13.1
/B-OUT: CN1.1 (B), IC1.11 (CH4_OUT), R44.1
/CL: C9.2, CL1.1, F1.1 (A)
/CR: B_1.1 (A), C4.2, CR1.1
/G-IN: G1.1, R4.1, R15.1
/G-OUT: CN1.3 (G), IC1.12 (CH3_OUT), R43.1
/OUT1: C14.1, IC2.1, R32.2, R36.1, R41.2
/OUT2: C15.1, IC2.7, R33.2, R35.1, R42.2
/PSG: C6.2, C7.2, D1.2 (C), P1.1
/R-IN: R1.1, R3.1, R12.1
/R-OUT: CN1.7 (R), IC1.13 (CH2_OUT), R40.1
/S75_0: IC1.14 (CH1_OUT), J4.1 (A)
/S75_1: J4.2 (B), R37.1
/SL: C16.2, CN1.8 (SL)
/SR: C17.2, CN1.9 (SR)
/SYNC-75: C22.2, CN1.4 (CVBS)
/SYNC-TTL: CN1.5 (SYNC), R2.1, R14.1, S1.1
/XL: C8.2, E1.1 (A), XL1.1
/XR: C1.1 (A), C5.2, XR1.1
/YL: C3.2, YL1.1
/YR: C2.2, YR1.1
GND: C18.2, C19.2, C20.2, C21.2, CN1.S1 (RTN), CN1.S2 (RTN), CN1.S3 (RTN), GND1.1, IC1.5 (GND), IC1.6 (DISABLE), IC2.4 (V-), R6.2, R7.2, R8.2, R9.2, R10.2, R11.2, R16.1, R17.1, R30.1, R31.1, R34.1, R39.1
unnamed: B_1.2 (B), R6.1
unnamed: C1.2 (B), R7.1
unnamed: C2.1, YR2.1 (A), YR3.1 (A), YR4.1 (A)
unnamed: C3.1, YL2.1 (A), YL3.1 (A), YL4.1 (A)
unnamed: C4.1, R18.1
unnamed: C5.1, R19.1
unnamed: C6.1, R20.1
unnamed: C7.1, R21.1
unnamed: C8.1, R22.1
unnamed: C9.1, R23.1
unnamed: C10.1, IC1.1 (CH1_IN)
unnamed: C10.2, R14.2, R16.2
unnamed: C11.1, IC1.3 (CH3_IN)
unnamed: C11.2, R15.2, R30.2
unnamed: C12.1, IC1.2 (CH2_IN)
unnamed: C12.2, R12.2, R17.2
unnamed: C13.1, IC1.4 (CH4_IN)
unnamed: C13.2, R13.2, R31.2
unnamed: C16.1, R35.2
unnamed: C17.1, R36.2
unnamed: C22.1, R37.2
unnamed: D1.1 (A), R8.1
unnamed: D1.3 (B), R9.1
unnamed: E1.2 (B), R10.1
unnamed: F1.2 (B), R11.1
unnamed: IC1.9 (BYPASS), LPF1.1 (A), R34.2
unnamed: J1.1, R40.2
unnamed: J2.1, R43.2
unnamed: J3.1, R44.2
unnamed: J11.1, R41.1
unnamed: J12.1, R42.1
unnamed: M1PU1.2 (B), R3.2, R4.2, R5.2
unnamed: R24.1, YR2.2 (B)
unnamed: R25.1, YR3.2 (B)
unnamed: R26.1, YR4.2 (B)
unnamed: R27.1, YL2.2 (B)
unnamed: R28.1, YL3.2 (B)
unnamed: R29.1, YL4.2 (B)

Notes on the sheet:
Video
Audio

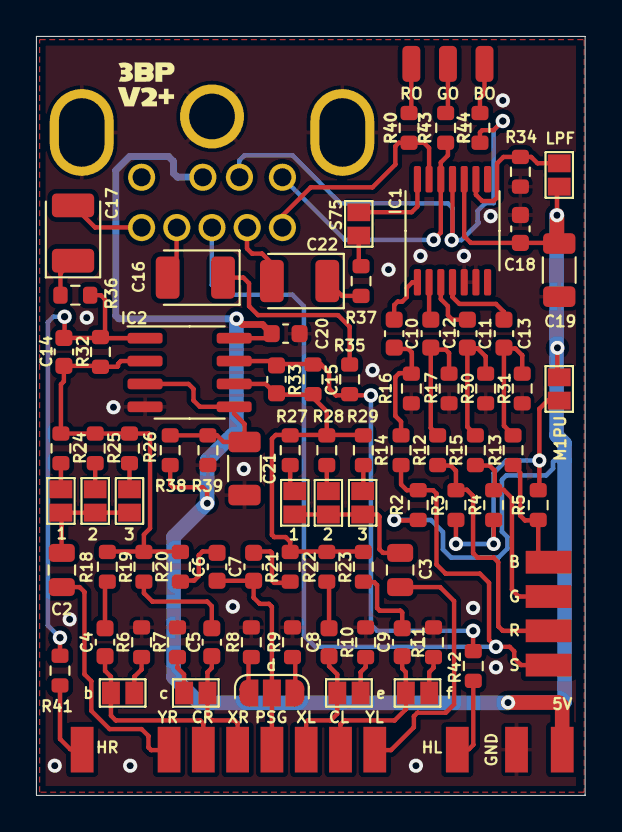
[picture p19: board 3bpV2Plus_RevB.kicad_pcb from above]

Board: 2 copper layers, 30.5 x 42.2 mm, 99 parts (1 on the bottom side), 64 nets.

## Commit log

2024-02-18 Add files via upload
    Corrected capacitor removal instructions for M1VA3
2025-02-02 Add files via upload
    Corrected errors (XL and XR swapped, need to remove CE10) on Model 3 VA1 installation procedure (Thanks Voultar)
    Corrected XL incorrect solder point - Thanks Duncan1111
2025-04-20 Add files via upload
    Corrected YR resistor removal and XL/XR solder points

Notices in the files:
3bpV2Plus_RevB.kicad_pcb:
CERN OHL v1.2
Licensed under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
